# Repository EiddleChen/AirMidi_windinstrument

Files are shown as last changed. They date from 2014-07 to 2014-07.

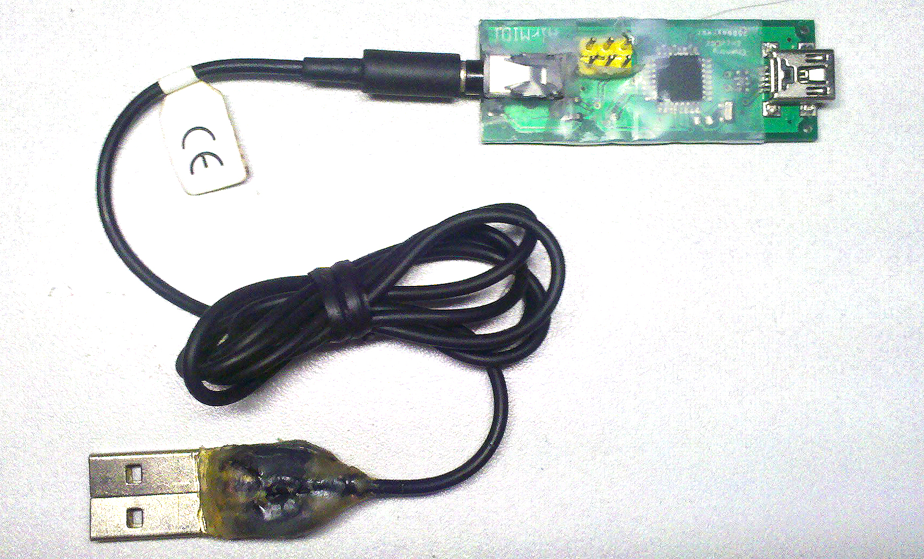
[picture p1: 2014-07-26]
preview.jpg

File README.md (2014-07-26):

AirMidi is the simplify and extend of
the Arduino platform, with the powerful Arduion library , the control of MIDI come to flexible
and simple.Moreover, with the LUFA framework, the development cost of USB protcool get
prodigious reduce, so the project can also simulate other USB device such as USB keyboard or
USB mouse.

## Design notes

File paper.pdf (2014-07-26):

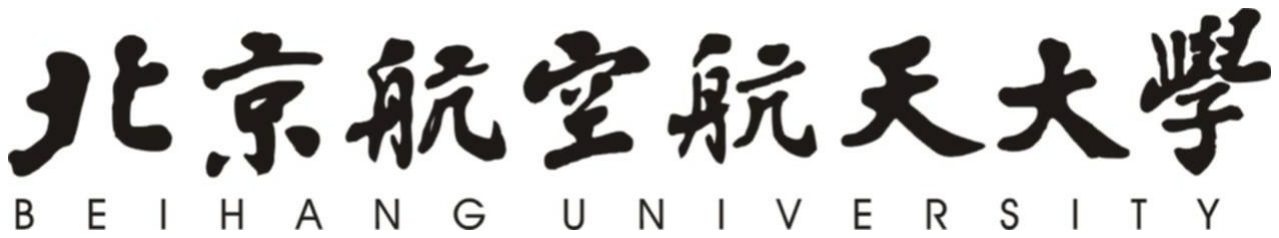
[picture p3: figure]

# AirMidi

## ——小巧灵活的 Midi 控制器

院系名称 | 仪器科学与光电工程
第一作者 | 陈怡同
学 号 | 10171036
第二作者 | 吴少晨
学 号 | 10171009

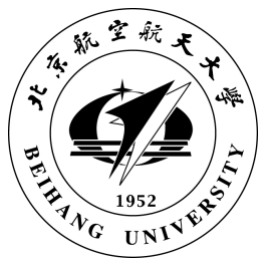
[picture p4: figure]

i

摘要

本文阐述了 AirMidi 发明的概念，背景，工作原理和使用方法，以及和上位机与 DAW 的协调。AirMidi 是在 Arduino 原型上的简化和扩展，并且依靠强大的 Arduino 库，使得 Midi 控制更加灵活和简单。同时，依靠 AVR 的 LUFA 库，使得 USB 协议开发大大的简化，因此 本项目还可以扩展为 USB 设备如鼠标键盘等。

关键词：AirMidi, Midi 控制器，AVR，

ii

Abstract

These document explans the concept, backgrounds,princliples and the usage of AirMidi, further more ,the commuication with DAW software on PCs.AirMidi is the simplify and extend of the Arduino platform, with the powerful Arduion library , the control of MIDI come to flexible and simple.Moreover, with the LUFA framework, the development cost of USB protcool get prodigious reduce, so the project can also simulate other USB device such as USB keyboard or USB mouse.

Keywords: AirMidi, Midi Controllor，AVR，

北京航空航天大学第二十三届“冯如杯”学生参赛作品

iii

目录

## 1. 绪论

### 1.1 背景及目的

随着数字化时代的到来，一些的新的音乐流派也在蓬勃发展。很多音乐工作室也引进了 很多数字化的设备来代替一些模拟设备以产生些新的效果。很多软件模拟的乐器和效果器在 一些场合被使用，与传统乐器或效果器交相辉映，编曲者混音时可以使用一些非传统的乐器 来制造新的效果。
AirMidi 就是一个低成本精简化的 USB Midi 控制器，它可以将任意电信号的模拟量直 接传送到任何音频工作站[1]软件中工作，而无需多余配置，完全的硬件实现，可以在任何 平台使用，达到商用的标准；而且所有数据的捕获都是实时并且可以定制的。比如说我希望 通过虚拟乐器模拟萨克斯的各种复杂气流吹奏技巧，而传统的 Midi 键盘只支持音符输入和 力度输入，并无法控制其他复杂技巧，而利用 Midi 参数映射来控制 Midi 键盘的调制轮或者 弯音轮又有很大的限制，因此在这个场合需要单一通道或多通道的的传感器信号来代替原来 的 Midi 参数，这样，同过 AirMidi 这样小巧的设备便可以很方便的得到这些效果。

### 1.2 国内外相关研究

Yamaha BC3A breath controler[2]：实现了气流流量的检测映射到 Midi 控制参数通道， 但是兼容设备受限，且定制性差；
Arduino[3]：提供了关于 ATmega328 等系列单片机的库函数，诸如 ADC，GPIO， Bootloader 等；提供了 PCB 布线的原理图和印制板电路，同时提供各个元件的参数。 LUFA[4]：提供了 Atmega8u2 等系列的 USB 协议控制库函数，可以通过头文件配置后， 编译出各种 USB 设备的固件。

### 1.3 课题的研究方法

通过学习 Arduino 的库函数基本了解 AVR 单片机的功能使用方法；
通过学习 Arduino 的电路原理图和布线图基本学会 PCB 布线；
通过学习 Arduino 在 eclipse AVR plugins 的环境的配置进而学会调用 LUFA 编译 USB 协 议的固件；
通过与学长交流，解决诸如刷写 AVR 熔丝位，焊接电路板，等技术细节问题； 通过 Blender 输出 3d 模型。

## 2. AirMidi 的工作原理

AirMidi 由硬件和固件共同实现，下面将分别解释其工作原理。

### 2.1 硬件部分

### 2.1.1 PCB 原理图

（附见图 1）
由 Arduino NANO 与 Arduino UNO 原型综合而成，通过实现选定正确的元件参数，并 在精简原有元件的基础上增加了 3.5mm 标准音频插接件。

### 2.1.2 PCB 布线图

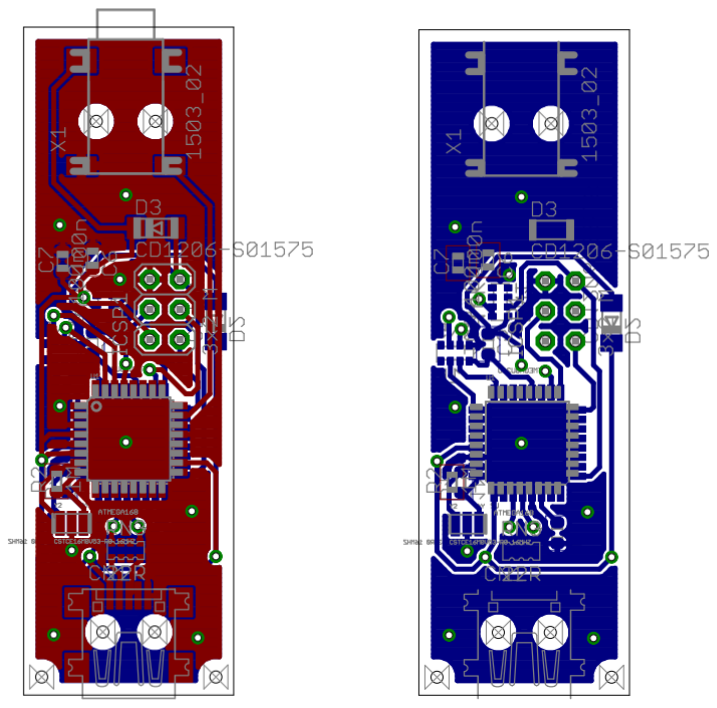
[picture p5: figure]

图 1 Top 层 | 图 2 Bottom 层

### 2.2 软件部分

Atmega328 高层代码样例 1

#include <MIDI.h>

/*
Basic I/O MIDI tutorial

by Franky
28/07/2009
*/
#define LED 13 | // LED pin on Arduino board

void setup() {
pinMode(LED, OUTPUT);
MIDI.begin(4); | // Launch MIDI with default options

// input channel is set to 4 }

void loop() {
if (MIDI.read()) {
digitalWrite(LED,HIGH); | // Blink the LED
MIDI.sendNoteOn(42,127,1); | // Send a Note (pitch 42, velo 127

on channel 1)

delay(1000); | // Wait for a second
MIDI.sendNoteOff(42,0,1); | // Stop the note
digitalWrite(LED,LOW);
}
}

## 参考文献

[1] 音频工作站软件(DAW) (http://en.wikipedia.org/wiki/Digital_audio_workstation)
[2] Yamaha BC3A (http://usa.yamaha.com/products/music-production/accessories/breathcontrollers/bc3a/?mode=model)
[3] Arduino offical site (http://www.arduino.cc/)
[4] LUFA (Lightweight USB Framework for AVRs, formerly known as MyUSB) (http://www.fourwalledcubicle.com/LUFA.php)

附录

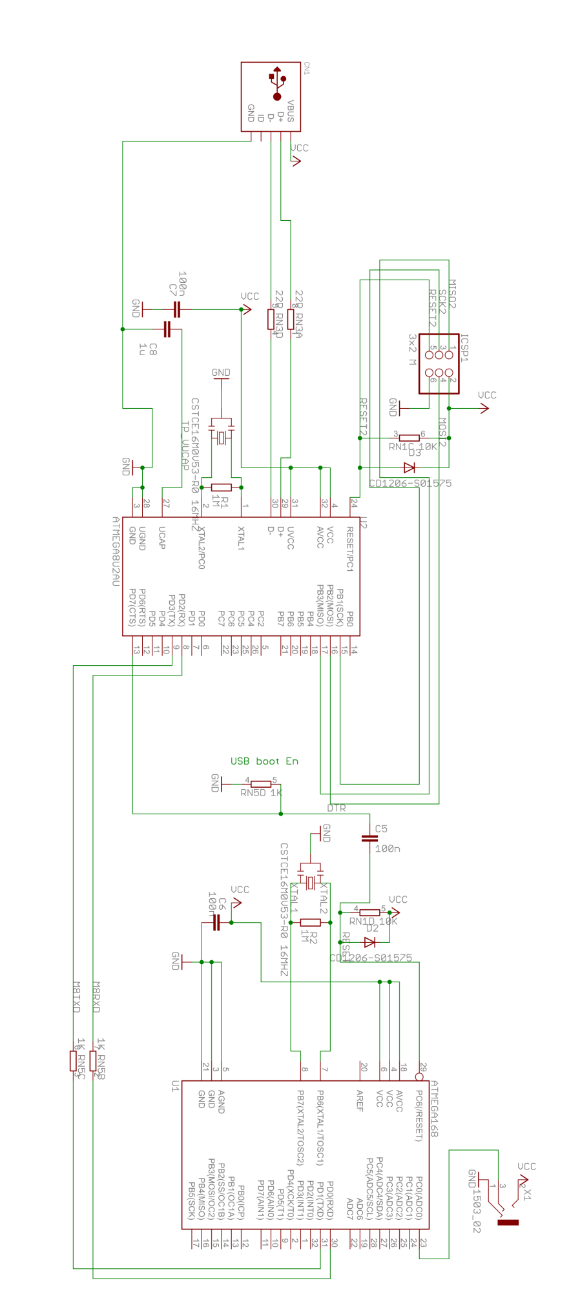
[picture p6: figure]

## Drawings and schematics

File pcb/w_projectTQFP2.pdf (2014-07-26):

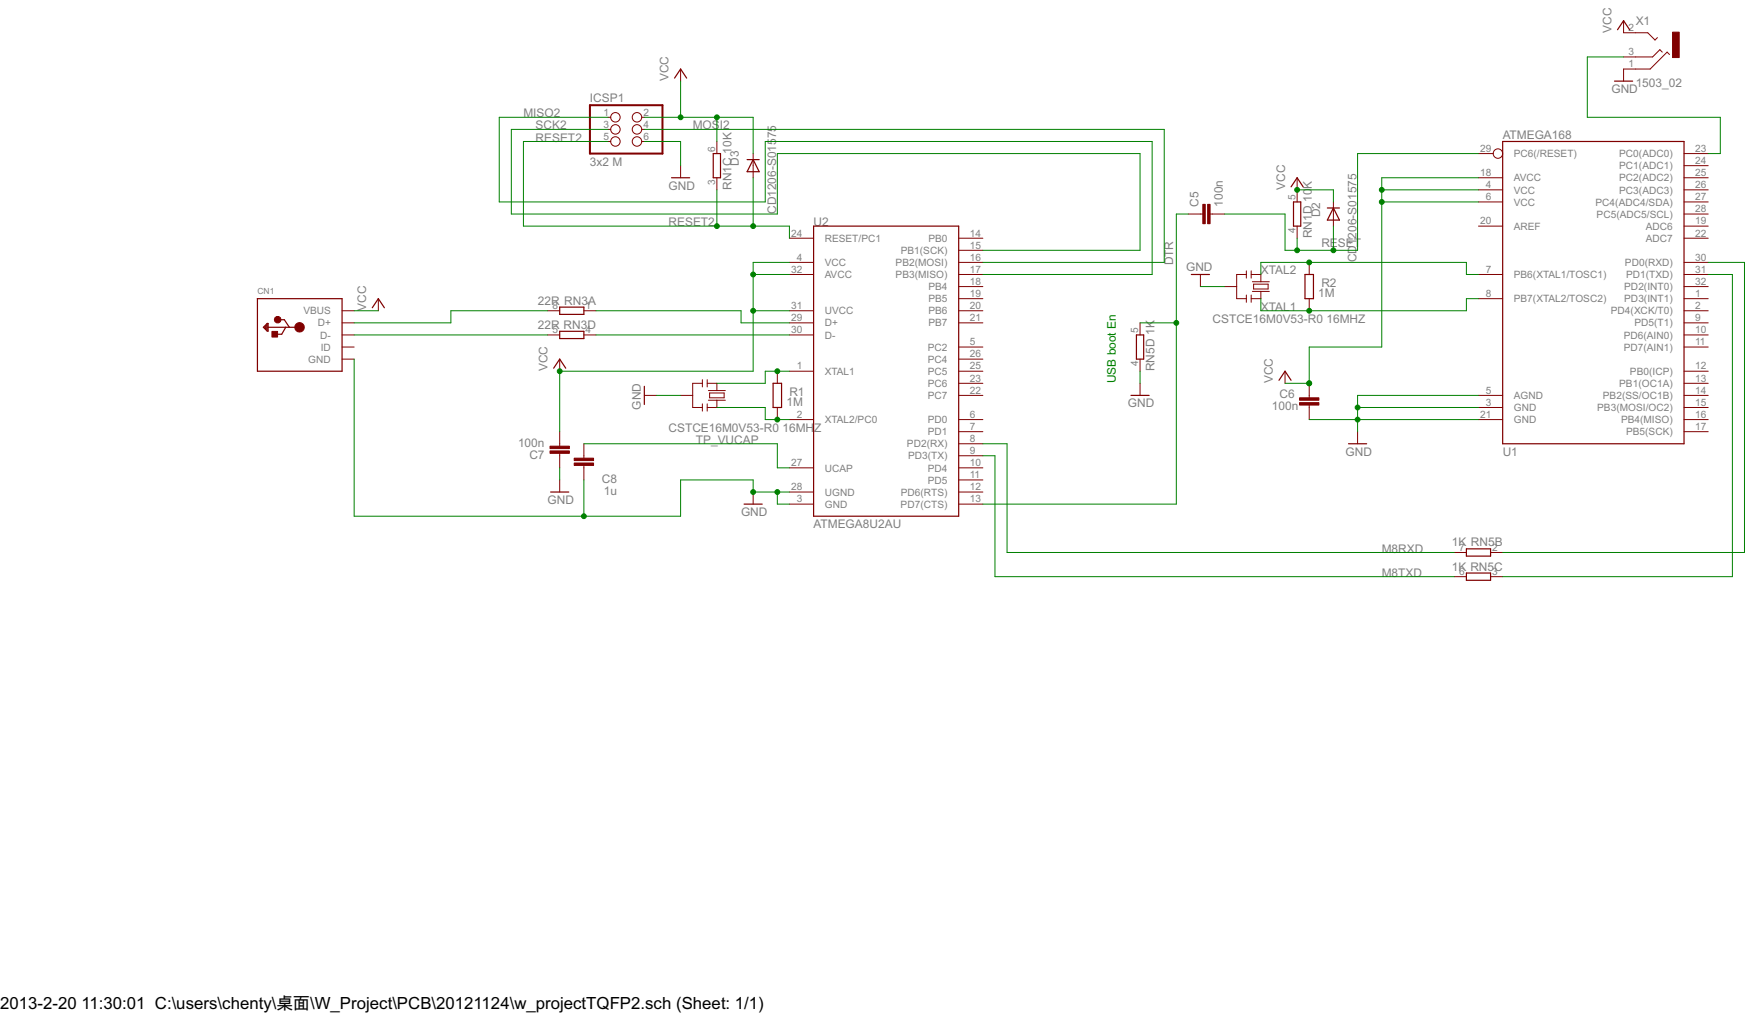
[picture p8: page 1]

2013-2-20 11:30:01 C:\users\chenty\桌面\W_Project\PCB\20121124\w_projectTQFP2.sch (Sheet: 1/1)

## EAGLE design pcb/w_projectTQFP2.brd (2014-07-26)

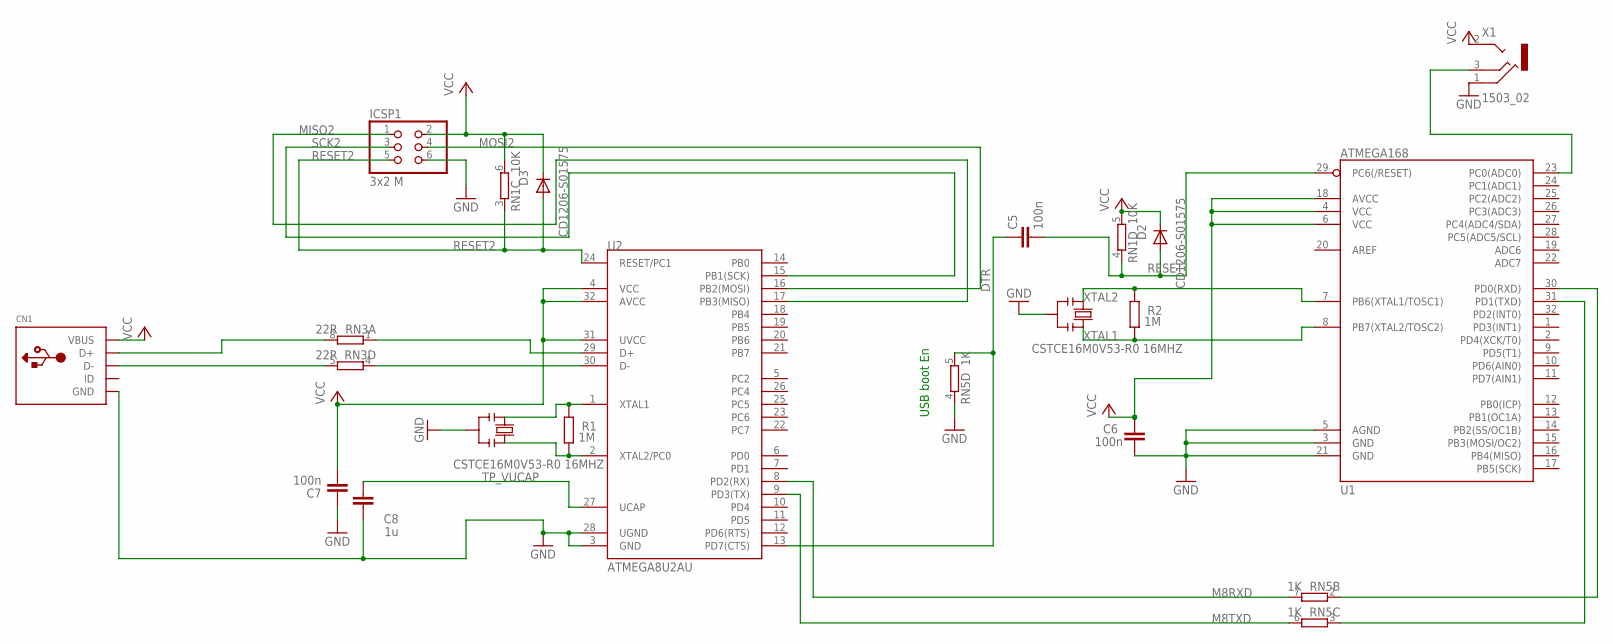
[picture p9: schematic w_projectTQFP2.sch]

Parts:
C5, C6, C7: 100n; C0603-ROUND; MPN 06033G104ZAT2A
C8: 1u; C0603-ROUND; MPN 1206YC105KAT2A
CN1: USBMINIB; USB-MINIB; MPN 67503-1030
D2, D3: CD1206-S01575; MINIMELF; MPN CD1206-S01575
ICSP1: 3x2 M; 2X03
R1, R2: 1M; R0603-ROUND; MPN CR0603-JW-105GLF
RN1: 10K; CAY16; MPN CAY16-1002F4LF.
RN3: 22R; CAY16; MPN CAY16-220J4LF
RN5: 1K; CAY16; MPN CAY16-102J4LF
U1: ATMEGA168; TQFP32-08; MPN ATMEGA328P-AU
U2: ATMEGA8U2AU; TQFP32-08; MPN ATMEGA16U2-AU
X1: 1503_02; MPN 1503 02
Y2, Y4: CSTCE16M0V53-R0 16MHZ; RESONATOR; MPN CSTCE16M0V53-R0

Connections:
D+: CN1.D+, RN3.8 (2)
DTR: C5.1, RN5.5 (2), U2.13 (PD7(CTS))
GND: C6.1, C7.2, C8.2, CN1.GND, ICSP1.6, RN5.4 (1), U1.3 (GND), U1.5 (AGND), U1.21 (GND), U2.3 (GND), U2.28 (UGND), X1.1, Y2.2, Y4.2
IO1: RN5.3 (1), U1.31 (PD1(TXD))
M8RXD: RN5.7 (2), U2.8 (PD2(RX))
M8TXD: RN5.6 (2), U2.9 (PD3(TX))
MISO2: ICSP1.1, U2.17 (PB3(MISO))
MOSI2: ICSP1.4, U2.16 (PB2(MOSI))
unnamed: RN5.2 (1), U1.30 (PD0(RXD))
unnamed: U1.23 (PC0(ADC0)), X1.3
unnamed: RN3.1, U2.29 (D+)
unnamed: CN1.D-, RN3.5 (2)
unnamed: R1.1, U2.2 (XTAL2/PC0), Y4.3
unnamed: RN3.4 (1), U2.30 (D-)
unnamed: R1.2, U2.1 (XTAL1), Y4.1
RESET: C5.2, D2.A, RN1.4 (1), U1.29 (PC6(/RESET))
RESET2: D3.A, ICSP1.5, RN1.3 (1), U2.24 (RESET/PC1)
SCK2: ICSP1.3, U2.15 (PB1(SCK))
TP_VUCAP: C8.1, U2.27 (UCAP)
VCC: C6.2, C7.1, CN1.VBUS, D2.C, D3.C, ICSP1.2, RN1.5 (2), RN1.6 (2), U1.4 (VCC), U1.6 (VCC), U1.18 (AVCC), U2.4 (VCC), U2.31 (UVCC), U2.32 (AVCC), X1.2
XTAL1: R2.1, U1.8 (PB7(XTAL2/TOSC2)), Y2.3
XTAL2: R2.2, U1.7 (PB6(XTAL1/TOSC1)), Y2.1

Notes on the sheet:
USB boot En

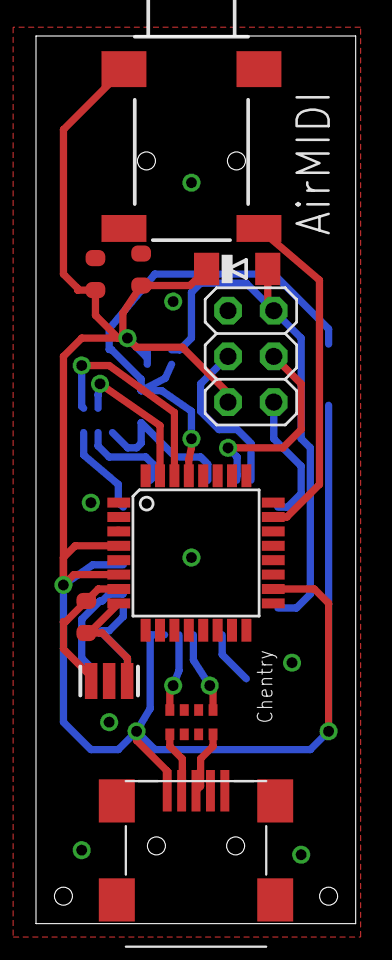
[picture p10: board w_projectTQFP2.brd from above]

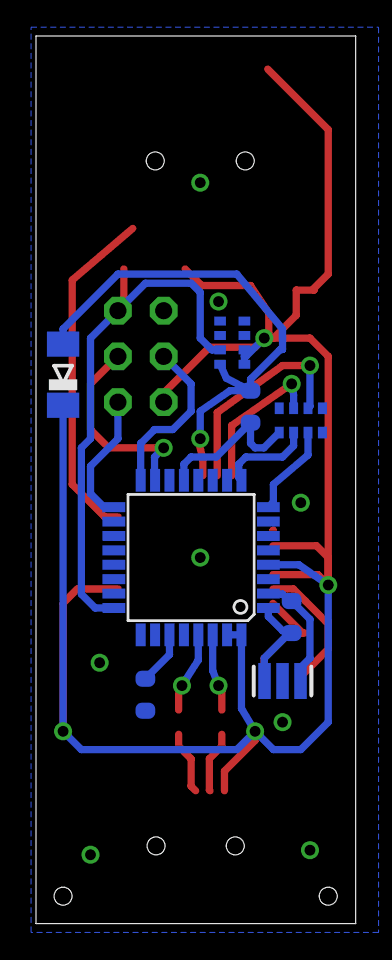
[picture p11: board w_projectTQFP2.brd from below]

Board: 2 copper layers, 17.8 x 49.3 mm, 18 parts (8 on the bottom side), 22 nets.

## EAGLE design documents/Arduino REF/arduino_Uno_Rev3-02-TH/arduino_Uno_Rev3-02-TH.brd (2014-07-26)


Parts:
AD: 6x1F-H8.5; 1X06
C1, C2, C4, C5, C6, C7: 100n; C0603-ROUND
C3, C8: 1u; C0603-ROUND
C9, C11: 22p; C0603-ROUND
D1: M7; SMB
D2, D3: CD1206-S01575; MINIMELF
F1: MF-MSMF050-2 500mA; L1812
FD1, FD2, FD3: FIDUCIALMOUNT; FIDUCIA-MOUNT
GROUND: SJ
ICSP, ICSP1: 3x2 M; 2X03
IOH: 10x1F-H8.5; 1X10
IOL: 8x1F-H8.5; 1X08
JP2: 2x2 M - NM; 2X02
L: YELLOW; CHIP-LED0805
L1: BLM21; 0805
ON: GREEN; CHIP-LED0805
PC1, PC2: 47u; PANASONIC_D
POWER: 8x1F-H8.5; 1X08
R1, R2: 1M; R0603-ROUND
RESET: TS42031-160R-TR-7260; TS42
RESET-EN: SJ
RN1: 10K; CAY16
RN2, RN4: 1K; CAY16
RN3: 22R; CAY16
RX: YELLOW; CHIP-LED0805
T1: FDN340P; SOT-23
TX: YELLOW; CHIP-LED0805
U1: NCP1117ST50T3G; SOT223
U2: LP2985-33DBVR; SOT23-DBV
U3: ATMEGA16U2-MU(R); MLF32
U5: LMV358IDGKR; MSOP08
U$1: DISCLAIMER
X1: POWERSUPPLY_DC21MMX; POWERSUPPLY_DC-21MM
X2: USB-B_TH; PN61729
Y1: 16MHz; QS
Y2: CSTCE16M0V53-R0 16MHZ; RESONATOR
Z1, Z2: CG0603MLC-05E; CT/CN0603
ZU4: ATMEGA328P-PU; DIL28-3

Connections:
5-GND: RESET.5 (5-GND)
+3V3: C3.2, POWER.4, U2.5 (OUT), U5.2 (-IN)
+5V: C1.2, C2.2, C6.2, C7.1, D2.C, D3.C, ICSP.2, ICSP1.2, PC2.+, POWER.2, POWER.5, RN1.3 (1), RN1.5 (2), RN2.2 (1), RN2.3 (1), RN4.3 (1), RN4.4 (1), T1.2 (S), U1.2 (OUT), U1.4 (OUT), U2.1 (IN), U2.3 (ON/!OFF), U3.4 (VCC), U3.32 (AVCC), U5.8 (V+), ZU4.7 (VCC), ZU4.20 (AVCC)
AD0: AD.1, ZU4.23 ((ADC0)PC0))
AD1: AD.2, ZU4.24 ((ADC1)PC1)
AD2: AD.3, ZU4.25 ((ADC2)PC2)
AD3: AD.4, ZU4.26 ((ADC3)PC3)
AD4/SDA: AD.5, IOH.9, ZU4.27 ((ADC4)PC4)
AD5/SCL: AD.6, IOH.10, ZU4.28 ((ADC5)PC5)
AREF: C4.2, IOH.8, ZU4.21 (AREF)
CMP: RN1.1, RN1.2 (1), U5.3 (+IN)
D+: RN3.5 (2), X2.3, Z1.1
D-: RN3.8 (2), X2.2, Z2.1
DTR: C5.1, RN2.4 (1), U3.13 ((CTS/HWB/AIN6/TO/INT7)PD7)
GATE_CMD: T1.3 (G), U5.1 (OUT)
GND: C1.1, C2.1, C3.1, C4.1, C6.1, C7.2, C9.2, C11.2, GROUND.1, ICSP.6, ICSP1.6, IOH.7, L.C, ON.C, PC1.-, PC2.-, POWER.6, POWER.7, RESET.1, RESET.2, RN1.7 (2), RN2.5 (2), U1.1 (GND/ADJ), U2.2 (GND), U3.3 (GND), U3.33 (PAD), U5.4 (V-), X1.1, X1.3, Y2.2, ZU4.8 (GND), ZU4.22 (AGND)
IO0: IOL.1, RN4.2 (1), ZU4.2 ((RXD)PD0)
IO1: IOL.2, RN4.1, ZU4.3 ((TXD)PD1)
IO2: IOL.3, ZU4.4 ((INT0)PD2)
IO3: IOL.4, ZU4.5 ((INT1)PD3)
IO4: IOL.5, ZU4.6 ((T0)PD4)
IO5: IOL.6, ZU4.11 ((T1)PD5)
IO6: IOL.7, ZU4.12 ((AIN0)PD6)
IO7: IOL.8, ZU4.13 ((AIN1)PD7)
IO8: IOH.1, ZU4.14 ((ICP)PB0)
IO9: IOH.2, ZU4.15 ((OC1)PB1)
L13: RN2.8 (2), U5.6 (-IN), U5.7 (OUT)
M8RXD: RN4.7 (2), U3.9 ((TXD1/INT3)PD3)
M8TXD: RN4.8 (2), U3.8 ((RXD1/AIN1/INT2)PD2)
MISO: ICSP.1, IOH.5, ZU4.18 ((MISO)PB4)
MISO2: ICSP1.1, U3.17 ((PD0/MISO/PCINT3)PB3)
MOSI: ICSP.4, IOH.4, ZU4.17 ((MOSI)PB3)
MOSI2: ICSP1.4, U3.16 ((PDI/MOSI/PCINT2)PB2)
unnamed: L.A, RN2.1
unnamed: ON.A, RN4.5 (2), RN4.6 (2)
unnamed: RN2.7 (2), RX.A
unnamed: RN2.6 (2), TX.A
PB4: JP2.1, U3.18 ((T1/PCINT4)PB4)
PB5: JP2.3, U3.19 ((PCINT5)PB5)
PB6: JP2.2, U3.20 ((PCINT6)PB6)
PB7: JP2.4, U3.21 ((PCINT7/OC0A/OC1C)PB7)
PWRIN: D1.A, X1.2
RD+: RN3.4 (1), U3.29 (D+)
RD-: RN3.1, U3.30 (D-)
RESET: C5.2, D2.A, ICSP.5, POWER.3, RESET.3, RESET.4, RESET-EN.1, RESET-EN.2, RN1.4 (1), ZU4.1 (RESET)
RESET2: D3.A, ICSP1.5, RN1.6 (2), U3.24 (RESET(PC1/DW))
RXLED: RX.C, U3.10 ((INT5/AIN3)PD4)
SCK: ICSP.3, IOH.6, U5.5 (+IN), ZU4.19 ((SCK)PB5)
SCK2: ICSP1.3, U3.15 ((SCLK/PCINT1)PB1)
SS: IOH.3, ZU4.16 ((SS)PB2)
TP_VUCAP: C8.1, U3.27 (UCAP)
TXLED: TX.C, U3.11 ((XCK/AIN4/PCINT12)PD5)
UGND: C8.2, GROUND.2, L1.1, U3.28 (UGND), X2.4
USBVCC: F1.1, T1.1 (D), U3.31 (UVCC)
USHIELD: L1.2, X2.P$1, X2.P$2, Z1.2, Z2.2
VIN: D1.C, PC1.+, POWER.8, RN1.8 (2), U1.3 (IN)
XT1: C9.1, R1.1, U3.1 (XTAL1), Y1.2
XT2: C11.1, R1.2, U3.2 (XTAL2(PC0)), Y1.1
XTAL1: R2.1, Y2.3, ZU4.9 (XTAL1)
XTAL2: R2.2, Y2.1, ZU4.10 (XTAL2)
XUSB: F1.2, X2.1

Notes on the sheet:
Arduino(TM) UNO Rev3
USB boot En
SDA
SCL
Use of the ARDUINO name must be compliant with http://www.arduino.cc/en/Main/Policy


Board: 2 copper layers, 68.6 x 53.3 mm, 53 parts (1 on the bottom side), 60 nets.

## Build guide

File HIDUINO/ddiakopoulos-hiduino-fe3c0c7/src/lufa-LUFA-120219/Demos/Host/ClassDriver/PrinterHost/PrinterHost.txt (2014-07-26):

/** \file
 *
 *  This file contains special DoxyGen information for the generation of the main page and other special
 *  documentation pages. It is not a project source file.
 */

/** \mainpage Printer Host Demo
 *
 *  \section Sec_Compat Demo Compatibility:
 *
 *  The following list indicates what microcontrollers are compatible with this demo.
 *
 *  - Series 7 USB AVRs (AT90USBxxx7)
 *
 *  \section Sec_Info USB Information:
 *
 *  The following table gives a rundown of the USB utilization of this demo.
 *
 *  <table>
 *   <tr>
 *    <td><b>USB Mode:</b></td>
 *    <td>Host</td>
 *   </tr>
 *   <tr>
 *    <td><b>USB Class:</b></td>
 *    <td>Printer Device</td>
 *   </tr>
 *   <tr>
 *    <td><b>USB Subclass:</b></td>
 *    <td>Bidirectional Protocol</td>
 *   </tr>
 *   <tr>
 *    <td><b>Relevant Standards:</b></td>
 *    <td>USBIF Printer Class Specification \n
 *        PCL Language Specification</td>
 *   </tr>
 *   <tr>
 *    <td><b>Usable Speeds:</b></td>
 *    <td>Low Speed Mode \n
 *        Full Speed Mode</td>
 *   </tr>
 *  </table>
 *
 *  \section Sec_Description Project Description:
 *
 *  Printer host demonstration application. This gives a simple reference
 *  application for implementing a USB Printer host, for USB printers using
 *  the bidirectional data encapsulation protocol and PCL language.
 *
 *  Upon connection of a compatible printer, the printer's device ID is sent
 *  to the AVR's serial port, and a simple test page is printed using the PCL
 *  printer language.
 *
 *  \section Sec_Options Project Options
 *
 *  The following defines can be found in this demo, which can control the demo behaviour when defined, or changed in value.
 *
 *  <table>
 *   <tr>
 *    <td>
 *     None
 *    </td>
 *   </tr>
 *  </table>
 */

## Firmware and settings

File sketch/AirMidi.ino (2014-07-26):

/***********************************************************************
 *  HIDUINO_MIDI_Example01
 *  MIDI Output
 *  by Dimitri Diakopoulos (http://www.dimitridiakopoulos.com)
 *  Music Technology: Interaction, Intelligence & Design, October 2011
 *************************************************************************/

#include <MIDI.h>
#define MaxAD 400
int MinAD = 243

int sensorValue;
int MIDICC,MIDICC_Last;


void setup() {
  MIDI.begin(MIDI_CHANNEL_OMNI);
  //Serial.begin(9600);
}

void loop() {
  sensorValue = analogRead(A0) - MinAD;
  if (sensorValue > MaxAD) sensorValue = MaxAD;
  else {
    if (sensorValue < MinAD) sensorValue = 0;
    else sensorValue -= MinAD;
  } 
  MIDICC = map(sensorValue,0,MaxAD,0,127);
  if (abs(MIDICC - MIDICC_Last) > 3){
    //Serial.println(MIDICC);
    MIDI.sendControlChange(2,MIDICC,1);
    MIDICC_Last = MIDICC;
  }
}

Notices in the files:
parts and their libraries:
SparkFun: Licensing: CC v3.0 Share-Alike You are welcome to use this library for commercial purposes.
